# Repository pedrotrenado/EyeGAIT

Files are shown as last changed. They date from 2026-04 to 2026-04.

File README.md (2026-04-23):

# EyeGAIT — Monitoring Device for Parkinson's Patients

> Academic project developed at the Department of Electronic Engineering  
> Universidad Politécnica de Madrid — Electronic Equipment Manufacturing (FEEL)

---

## Description

EyeGAIT is an **intelligent smart insole** designed to monitor patients with Parkinson's disease, aiming to assist in the early detection and personalized treatment of gait disorders.

The Spanish Society of Neurology (SEN) estimates that the number of affected individuals will double within 20 years and triple by 2050, making wearable devices like this one a highly valuable clinical tool.

---

## System Architecture

The system is composed of the following modules:

| Module | Component | Function |
|---|---|---|
| Microcontroller | CC2640R2F | Central processing + RF (Bluetooth Low Energy) |
| IMU | BMI323 | Accelerometer, magnetometer, gyroscope (SPI) |
| Environmental sensor | BME680 | Temperature, humidity, pressure, gas (SPI/I2C) |
| Battery management | BQ24232 | LiPo battery charger |
| Voltage regulator | AP7361-33E | Linear regulator 3.3V / 1A |
| Actuators | Motor + Buzzer | Haptic and audio feedback (PWM) |
| Communication | USB Micro-B | Programming and charging |
| Oscillators | 32.768 kHz + 24 MHz | RTC and main clock |

---

## PCB

### Manufacturing Specifications

| Parameter | Value |
|---|---|
| Base material | FR-4 Standard TG 135–140 |
| Number of layers | 4 |
| Dimensions | 35 × 35 mm |
| Thickness | 1.6 mm |
| Solder mask color | Green |
| Silkscreen | White |
| Surface finish | HASL (with lead) |
| Outer copper weight | 1 oz |
| Inner copper weight | 0.5 oz |
| Min via (hole/pad) | 0.3 mm / 0.45 mm |
| Via covering | Tented |
| Board outline tolerance | ±0.2 mm |
| Impedance control | No |
| Gold Fingers | No |

### PCB Views

| Top Layer | Bottom Layer |
|---|---|
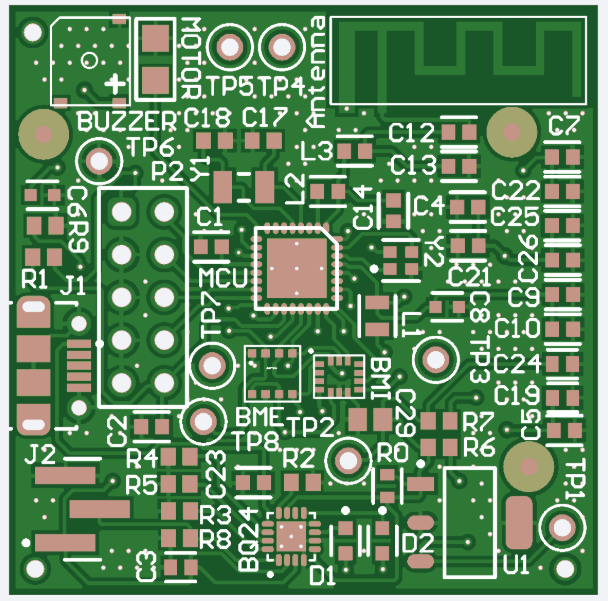
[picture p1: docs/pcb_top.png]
Top
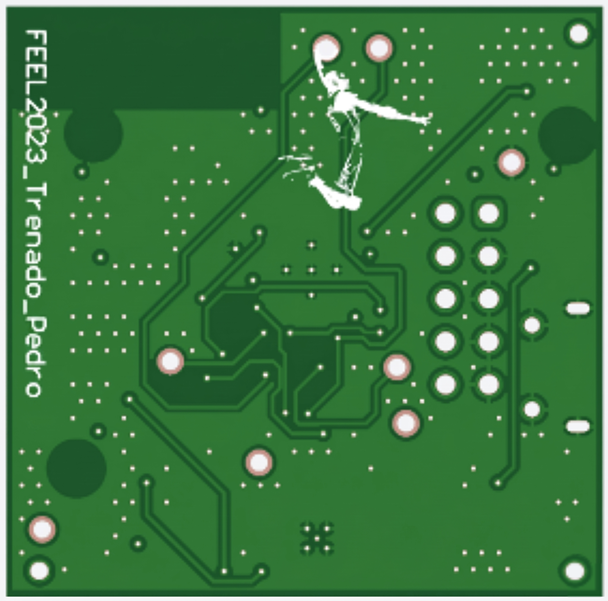
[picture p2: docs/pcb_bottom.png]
Bottom
|  |  |

> Designed in Altium Designer. PCB ID: `FEEL2023_Trenado_Pedro`

---

## BOM (Bill of Materials) — Summary

| Qty | Component | Reference | Description |
|---|---|---|---|
| 1 | CC2640R2FRHB | MCU | TI BLE Microcontroller |
| 1 | BMI323 | BMI | 6-axis IMU |
| 1 | BME680 | BME | 4-in-1 sensor (T, H, P, Gas) |
| 1 | BQ24232 | BQ24 | LiPo battery charger |
| 1 | AP7361-33E | U1 | 3.3V linear regulator |
| 1 | SMD Buzzer | BUZZER | Surface mount buzzer |
| 1 | Motor | MOTOR | Vibration motor |
| 1 | USB Micro-B | J1 | USB connector |
| 10 | 100 nF / 0603 | C2,C4,C5… | Decoupling capacitors |
| 3 | 4.7 µF / 0603 | C3,C19,C24 | Filter capacitors |
| 2 | 10 µF / 0603 | C6,C8 | Bulk capacitors |
| 8 | Test Points | TP1–TP8 | DFT test points |
| 2 | Green LED | D1,D2 | Status indicators |
| 2 | Crystal | Y1,Y2 | 32.768 kHz + 24 MHz |
| ~10 | Resistors 0603 | R1–R9 | Various values |
| 2 | 180 nH inductors | L2,L3 | RF filters |
| 1 | 10 µH inductor | L1 | Regulator filter |

Full BOM available at [`/hardware/BOM.pdf`](hardware/BOM.pdf)

---

## PRD (Product Requirements Document)

| Requirement | Value |
|---|---|
| DFT | Accessible test points |
| Size | 35 × 35 mm (target: 30 × 30 mm) |
| Battery life | 1 day – 1 week |
| Operating temperature | 0 °C – 65 °C |
| Target sales volume | Hundreds of thousands of units |
| Target cost | €10 – €20 |
| Time to market | 4 months |
| Certifications | CE |

---

## Repository Structure

```
EyeGAIT/
├── hardware/
│   ├── BOM.pdf
│   ├── schematic/
│   ├── pcb/
│   └── gerbers/
├── docs/
│   ├── pcb_top.png
│   ├── pcb_bottom.png
│   └── FEEL-01-propuesta_proyecto.pdf
└── README.md
```

---

## Team

Project developed for the course **Electronic Equipment Manufacturing (FEEL)**  
Department of Electronic Engineering — Universidad Politécnica de Madrid  
Author: Pedro Trenado

---

## License

This project is for academic use only.

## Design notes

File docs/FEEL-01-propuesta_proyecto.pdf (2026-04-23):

Departamento de

## Ingeniería

### Electrónica

Universidad Politécnica de Madrid

# Fabricación de Equipos Electrónicos

# Propuesta proyecto

### Electrónica

Universidad Politécnica de Madrid

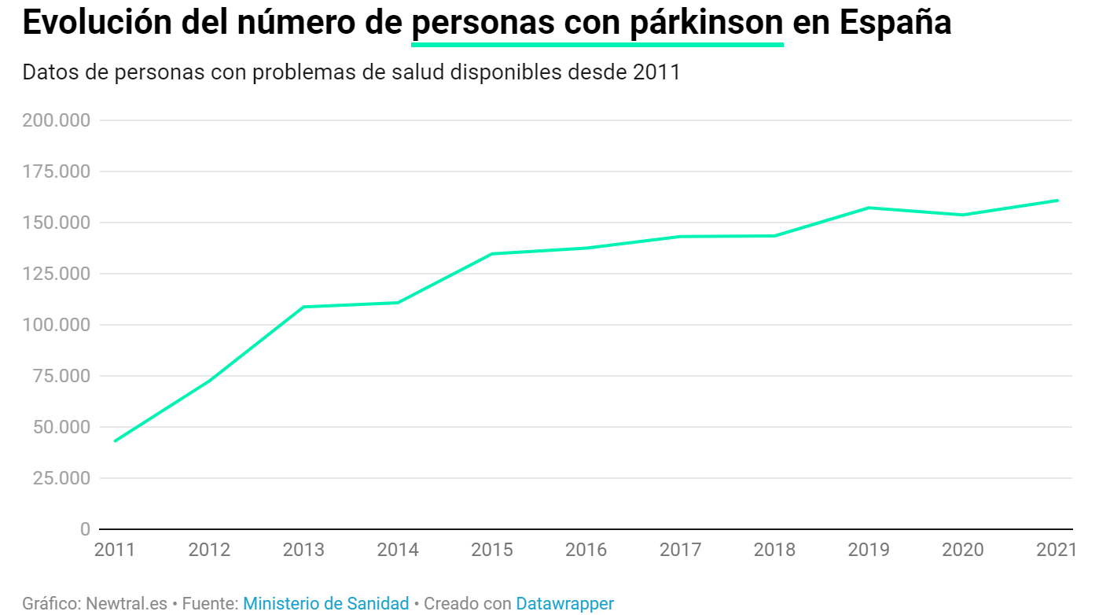
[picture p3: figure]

### Electrónica

Universidad Politécnica de Madrid

# EyeGAIT – Dispositivo de monitorización para pacientes de Parkinson

# - La SEN estima que el número de afectados se

duplicará en 20 años y se triplicará en 2050.

# “La enfermedad de Parkinson es una enfermedad caracterizada principalmente porque los pacientes presentan temblor de reposo, rigidez, pérdida de

habilidad o rapidez para realizar funciones motoras,

# trastornos posturales y/o trastorno de la marcha. Sin

embargo, un paciente con Parkinson puede desarrollar,

# entre 5 y 10 años antes del comienzo de los síntomas motores”

### Electrónica

Universidad Politécnica de Madrid

# EyeGAIT – Dispositivo de monitorización para pacientes de Parkinson

# - Plantilla inteligente que permita monitorizar a pacientes de Parkinson para la ayuda a la detección temprana y

el tratamiento personalizado.

### Electrónica

Universidad Politécnica de Madrid

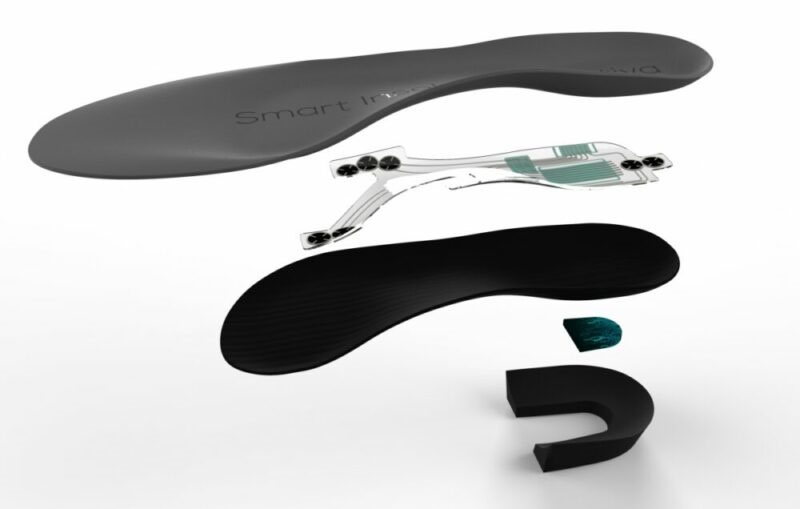
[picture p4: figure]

### Electrónica

Universidad Politécnica de Madrid

# Ciclo de diseño

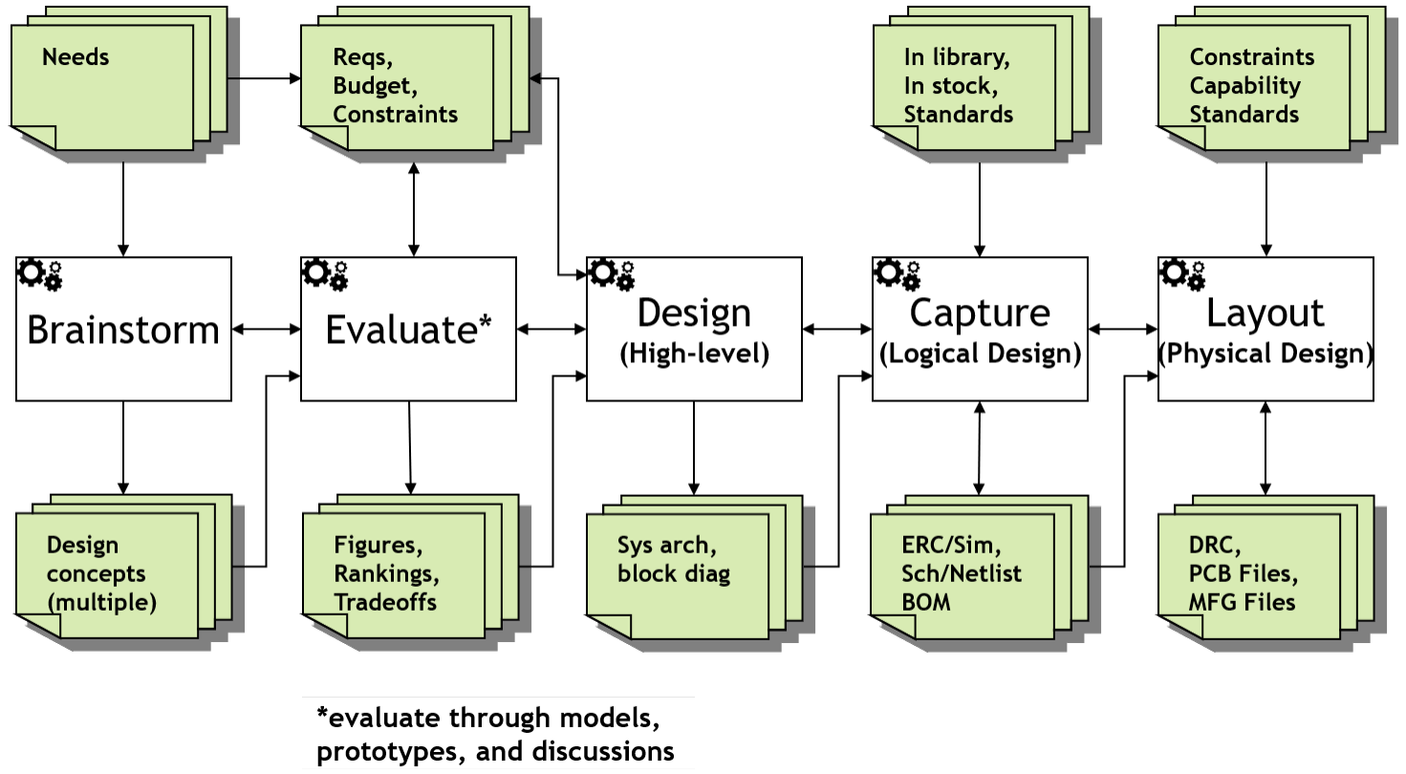
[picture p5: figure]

### Electrónica

Universidad Politécnica de Madrid

# EyeGait

# - PRD

### Electrónica

Universidad Politécnica de Madrid

# PRD - EyeGait

# - DFT: - Tamaño: - Autonomía: - Temperatura de operación: - Edad de público objetivo: - Estimamos vender: - Coste objetivo: - Time to market:

# - Métricas para saber que se cumplen

### Electrónica

Universidad Politécnica de Madrid

# PRD - Hefesto

# - DFT: Puntos de prueba - Tamaño: 3x3 (5x5) cm - Autonomía: 1 día – 1 semana - Temperatura de operación: 0- 65 - Edad de público objetivo: --- Estimamos vender: Cientos de Miles - Coste objetivo: 10-20 Euros - Time to market: 4 meses

# - Métricas para saber que se cumplen

### Electrónica

Universidad Politécnica de Madrid

# EyeGait

- RF

# - Microcontrolador bajo consumo - IMU, temperatura, humedad - Batería, energy harvesting???

### Electrónica

Universidad Politécnica de Madrid

# EyeGait

- CE

# - Fiducials - 4 Mechanical holes

### Electrónica

Universidad Politécnica de Madrid

# EyeGait

# - Constantes vitales - Patrones IA - Wearable - Movimiento (todos)

# - Peso en cada pierna - Contracciones musculares - Peso por pie

# - Impulsos SN - Batería modular - Aviso diagnóstico - Harvesting?

### Electrónica

# Módulos de un sistema HW

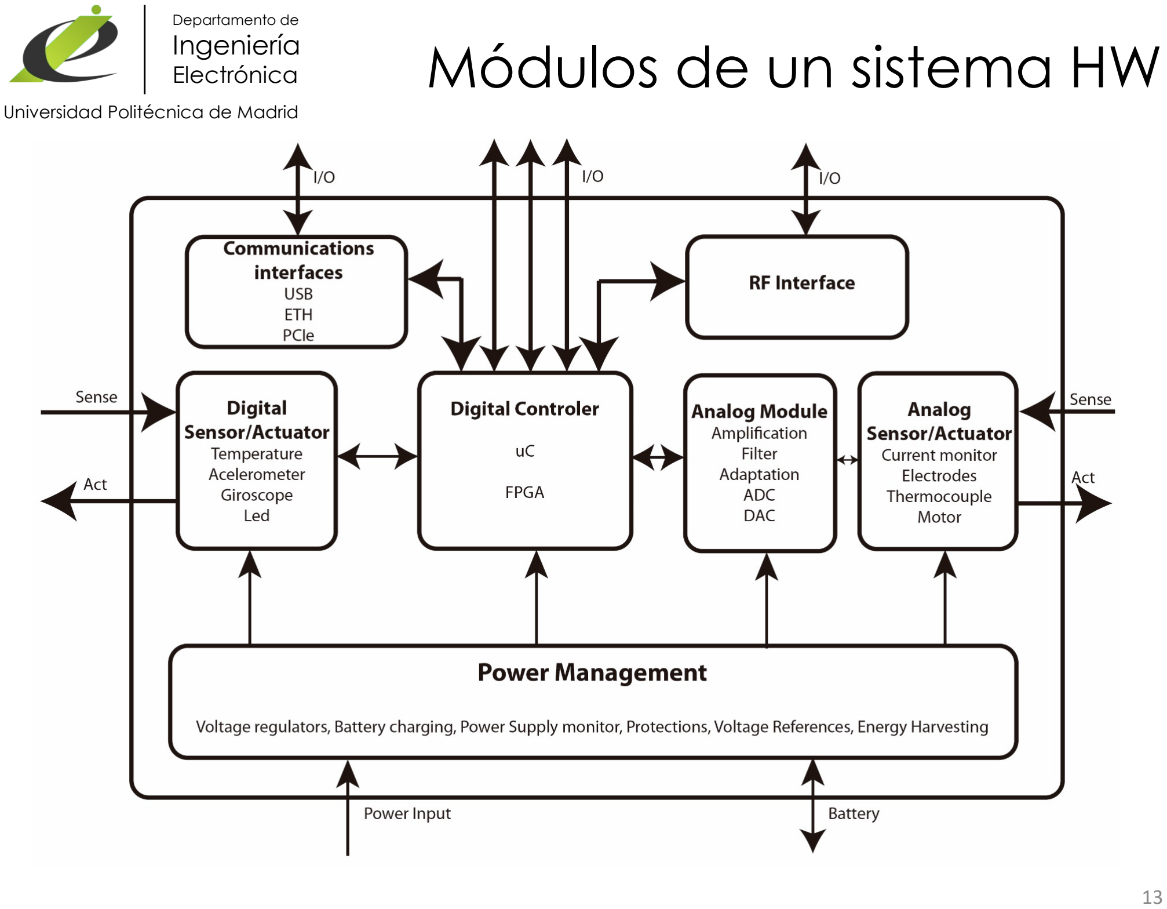
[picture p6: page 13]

Universidad Politécnica de Madrid

### Electrónica

Universidad Politécnica de Madrid

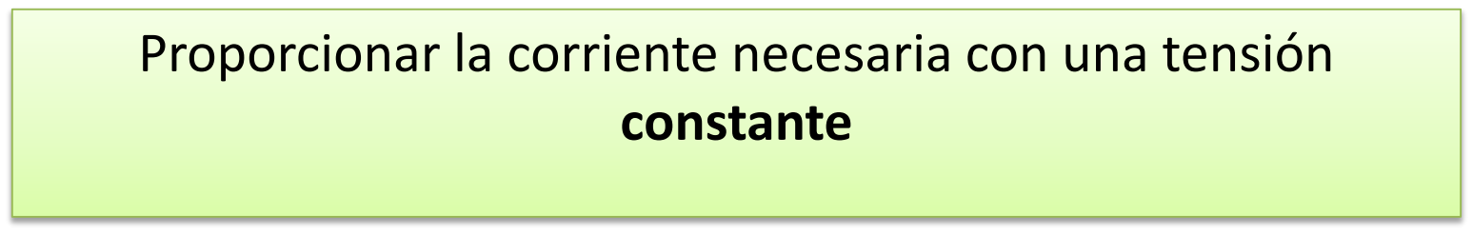
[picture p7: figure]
constante

# - Ojo! Algunas veces se quiere lo contrario: Proporcionar la tensión necesaria a corriente constante (carga de baterías, energy harvesting…)

# Alimentación del sistema

# - Objetivo del módulo de alimentación del sistema

# Proporcionar la corriente necesaria con una tensión

### Electrónica

Universidad Politécnica de Madrid

# - Solución

# - Reguladores de tensión lineales

# - Reguladores de tensión conmutados

# Alimentación del sistema

## - Implicaciones

# - La tensión tiene que ser constante: NO rizado, NO ruido

# - Deben poder darse picos de corriente sin que caiga la tensión

# - Tiene que ser lo más eficiente posible, sino se calienta

### Electrónica

# Alimentación del sistema

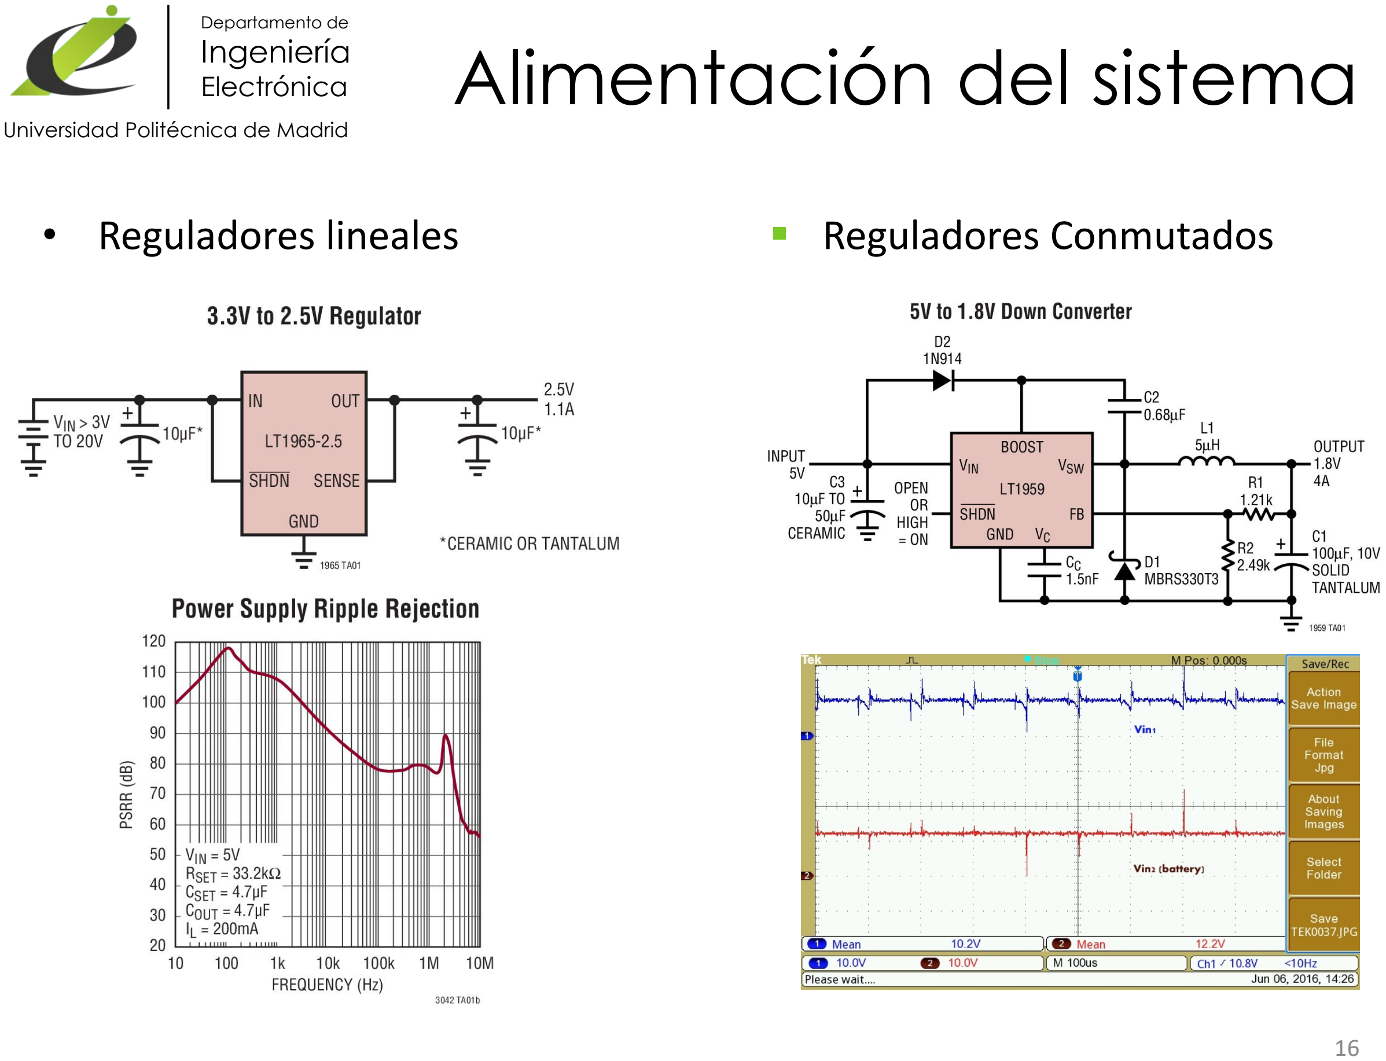
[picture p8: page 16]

Universidad Politécnica de Madrid
- Reguladores lineales | ▪ Reguladores Conmutados

### Electrónica

Universidad Politécnica de Madrid

## - *** Existen reguladores conmutados de bajo consumo, pero su rizado es aún mayor

# Alimentación del sistema

| Linear Regulator | Switching Regulator
THD+N | Low ~10uV | High ~10mV
Efficiency | 50% | 90%
External Components | Few and small | Many and big
Quiescient Current | ~10 uA | ~100 uA (***)
Output current | Low | Large
Heat Dissipation | Critical | Only for large currents
Dynamic Behaviour | Stable | Care should be taken

### Electrónica

Universidad Politécnica de Madrid
- Serial Communication Interfaces (SCI): RS-232, RS-422, RS-485 etc.

# - Synchronous Serial Communication Interface: I2C, SPI, SSC and ESSI (Enhanced Synchronous Serial Interface) - Universal Serial Bus (USB) - Multi Media Cards (SD Cards, Compact Flash etc.)

- Networks: Ethernet, LonWorks, etc.
- Fieldbuses: CAN-Bus, LIN-Bus, PROFIBUS, etc.

# - Discrete IO: aka General Purpose Input/Output (GPIO)

- Debugging: JTAG, ISP, ICSP, BDM Port, BITP, and DP9 ports.

# Interfaces

### Electrónica

Universidad Politécnica de Madrid

# SPI

# - Serial Peripheral Interface

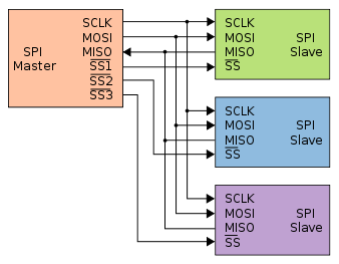
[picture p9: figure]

# – Desarrollado en los 80 por Motorola

# - 4 líneas

# – SCLK – reloj – MOSI – Master Output Slave Input – MISO – Master Input Slave Output – CS/SS – Chip/Slave Select

# - Bus maestro-esclavo

# – El maestro pone el reloj

# - Síncrono

# - Comunicación full-duplex

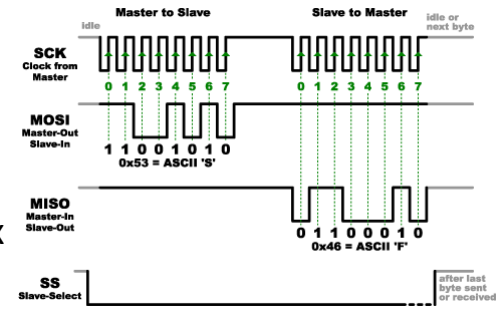
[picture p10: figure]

# – Hay versiones de 3 hilos (half-duplex)

### Electrónica

Universidad Politécnica de Madrid

I

2C

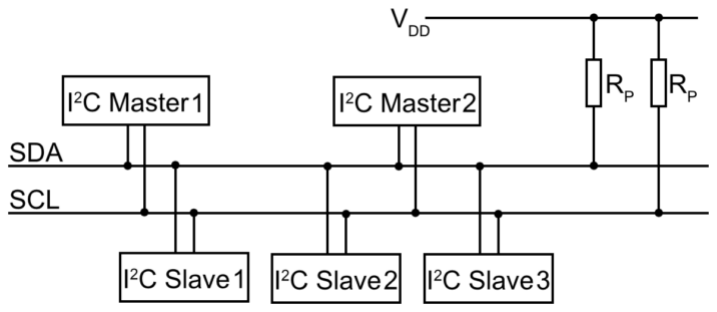
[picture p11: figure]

# - Inter-Integrated Circuit

# – Desarrollado en 1982 por Philips

# - 2 líneas

# – SCL – reloj – SDA – datos

# - Bus maestro-esclavo

# – Permite multi-máster: arbitration – Basado en direcciones

# - Síncrono - Half-duplex

# - Posibilidad de lecturas/escrituras burst: START-STOP - Mucho más lento que SPI, pero más escalable

### Electrónica

# Block diagram

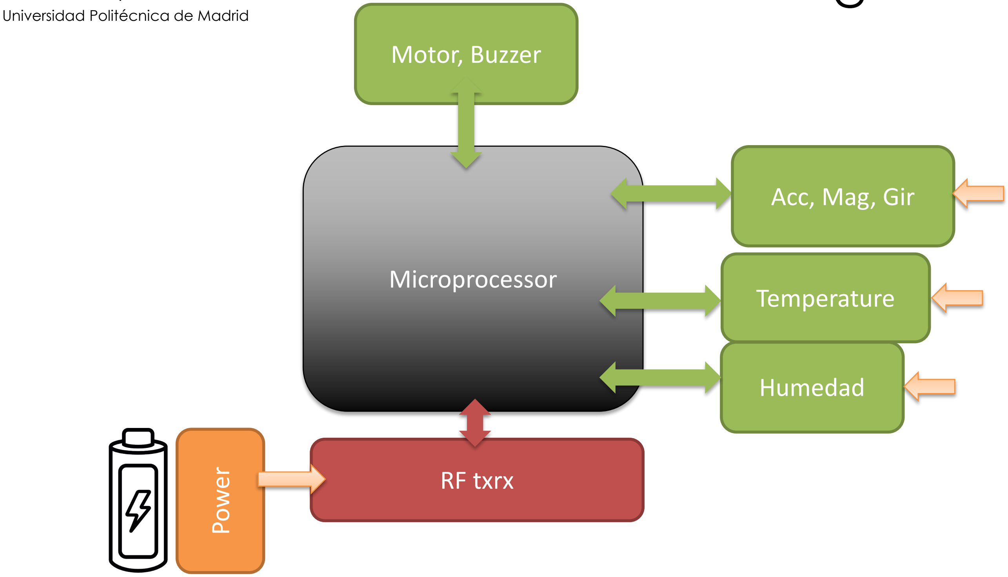
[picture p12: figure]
Universidad Politécnica de Madrid; Microprocessor; Humedad; RF txrx; Power; Temperature; Acc, Mag, Gir; Motor, Buzzer

### Electrónica

# Block diagram

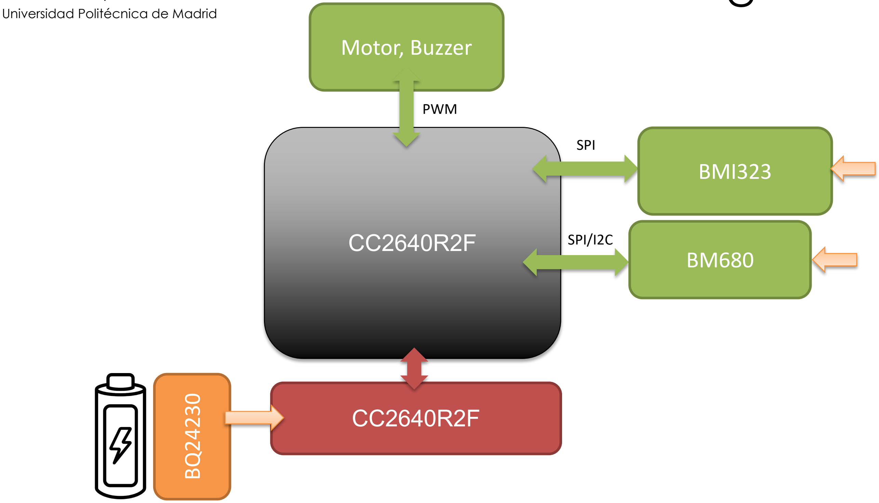
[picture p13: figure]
Universidad Politécnica de Madrid; BMI323; Motor, Buzzer; PWM; SPI/I2C; SPI

### Electrónica

Universidad Politécnica de Madrid

# Preguntas

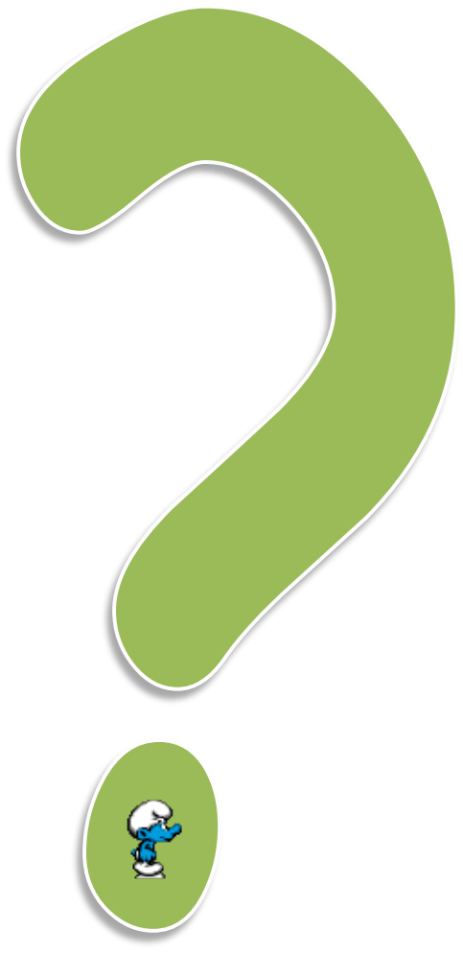
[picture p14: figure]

### Electrónica

Universidad Politécnica de Madrid

# Preguntas

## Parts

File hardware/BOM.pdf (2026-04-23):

Comment | Description | Designator | Footprint | LibRef | Quantity
BME680_Sen_4in1 | | BME | BME_LGA8 | BME680_Sen_4in1 | 1
BMI323 | | BMI | BMI323 | BMI323 | 1
BQ24232 | | BQ24 | VQFN | BQ24232 | 1
Surface_Mount_Buzzer | | BUZZER | buzzer | Surface_Mount_Buzzer | 1
1 µF | General Purpose Ceramic Capacitor, 0603, 1uF, +80/-20 %, Y5V, +22%/ –82%, 10V | C1, C23 | FP-0603-L_1_6_0_15-W_0_81-IPC_C | CMP-2006-04569-2 | 2
100 nF | Automotive Ceramic Capacitor, 0603, 100nF, 10%, X7R, 15%, 50V | C2, C4, C5, C7, C9, C10, C21, C22, C25, C26 | FP-0603-L_1_6_0_15-W_0_81-IPC_C | CMP-2006-04386-2 | 10
4.7 µF | CAP CER 4.7UF 6.3V X5R 0603 | C3, C19, C24 | FP-C0603-CG-MFG | CMP-2006-02256-2 | 3
10 µF | Multilayer Ceramic Capacitor 10uF 16V X5R 20% SMD 0603 T/ R | C6, C8 | FP-0603-L_1_6_0_2-W_0_8_0-MFG | CMP-2000-06226-4 | 2
TBD | General Purpose Ceramic Capacitor, 0603, 1uF, +80/-20 %, Y5V, +22%/ –82%, 10V | C12, C13, C14 | FP-0603-L_1_6_0_15-W_0_81-IPC_C | CMP-2006-04569-2 | 3
12 pF | | C17, C18 | CAPC1608X73X35LL10 T15 | CMP-2006-04614-1 | 2
1 µF | | C29 | CAPC2013X135X45LL10 T25 | CMP-1036-04761-2 | 1
| LED GREEN CLEAR CHIP SMD | D1, D2 | FP-LTST-C190GKT-MFG | CMP-22017-000005-2 | 2
105017-0001 | Micro-USB B Receptacle, Right Angle, Bottom Mount, Surface Mount, with Solder Tabs, -30 to 85 degC, 5-Pin USB, RoHS, Tape and Reel | J1 | USB-MICRO-B_V | CMP-2000-05827-1 | 1
TMM-103-01-L-S-SM | CONN HEADER SMD 3POS 2MM | J2 | FP-TMM-103-01-L-S-SM-MFG | CMP-02766-001735-1 | 1
10 µH | FIXED IND 2.2UH 1.2A 228 MOHM | L1 | FP-DFE201210U-MFG | CMP-06042-016271-1 | 1
TBD | Multilayer Type Inductor for General Circuits, 0603 (1608), 180nH, 10%, 0.6Ω, 50mA | L2, L3 | FP-LQM18NN_00-IPC_C | CMP-06042-016946-1 | 2
CC2640R2FRHB | | MCU | CC2640 | CC2640R2FRHB | 1
MOTOR | | MOTOR | Motor | MOTOR | 1
61301021121 | | P2 | 61301021121 | CMP-1502-01084-2 | 1
1K | Chip Resistor, 0 Ohm, Jumper, 100 mW, -55 to 155 degC, 0603 (1608 Metric), RoHS, Tape and Reel | R1, R8 | RESC1609X50X30NL8T 20 | CMP-2000-03816-5 | 2
3.2K | Chip Resistor, 0 Ohm, Jumper, 100 mW, -55 to 155 degC, 0603 (1608 Metric), RoHS, Tape and Reel | R2 | RESC1609X50X30NL8T 20 | CMP-2000-03816-5 | 1
1.8K | Chip Resistor, 0 Ohm, Jumper, 100 mW, -55 to 155 degC, 0603 (1608 Metric), RoHS, Tape and Reel | R3 | RESC1609X50X30NL8T 20 | CMP-2000-03816-5 | 1
18K | Chip Resistor, 0 Ohm, Jumper, 100 mW, -55 to 155 degC, 0603 (1608 Metric), RoHS, Tape and Reel | R4 | RESC1609X50X30NL8T 20 | CMP-2000-03816-5 | 1
3.9K | Chip Resistor, 0 Ohm, Jumper, 100 mW, -55 to 155 degC, 0603 (1608 Metric), RoHS, Tape and Reel | R5 | RESC1609X50X30NL8T 20 | CMP-2000-03816-5 | 1
1.5K | Chip Resistor, 0 Ohm, Jumper, 100 mW, -55 to 155 degC, 0603 (1608 Metric), RoHS, Tape and Reel | R6, R7 | RESC1609X50X30NL8T 20 | CMP-2000-03816-5 | 2
2M | Chip Resistor, 0 Ohm, Jumper, 100 mW, -55 to 155 degC, 0603 (1608 Metric), RoHS, Tape and Reel | R9 | RESC1609X50X30NL8T 20 | CMP-2000-03816-5 | 1
5002 | PC TEST POINT MINIATURE WHITE | TP1, TP2, TP3, TP4, TP5, TP6, TP7, TP8 | FP-5002-MFG | CMP-2000-05182-2 | 8
AP7361-33E-13 | IC REG LINEAR 3.3V 1A SOT223 | U1 | FP-SOT223-IPC_C | CMP-12756-000024-1 | 1
32.768KHZ | Crystal 32.768kHz ±20ppm (Tol) 12.5pF FUND 70kΩ 2-Pin CSMD T/R | Y1 | FP-ABS07-MFG | CMP-0447-00001-4 | 1
24 MHZ | Crystal 24MHz ±20ppm 10pF SMD-4 2mm x 1.6mm | Y2 | FP-ABM11-MFG | CMP-27762-002563-1 | 1
